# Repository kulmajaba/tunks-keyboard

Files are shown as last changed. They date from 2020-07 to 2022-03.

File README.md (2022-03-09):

# Tunks keyboards
> Formerly: The project that will someday be the ultimate command center upgrade

This repo contains the Tunks series keyboard schematics, born as an experiment to make a macro keyboard for editing, gaming and testing mechanical switches.

## Roadmap

Companion app: a combination of hardware and software allowing the user to control programs like Discord and OBS as well as receive visual feedback in the form of "tally lights".
Keyboard shortcuts are fragile and unpredictable, and software like AutoHotKey is considered cheating software by a lot of anti-cheat utilities, regardless of what you do with it.

**Resources**

- Discord: mute and deaf states, and setting the states instead of toggling: https://discordapp.com/developers/docs/game-sdk/discord-voice
- OBS: See which outputs are in use in the current scene (we're interested in camera, display capture and microphone), switch between scenes: https://obsproject.com/docs/
- QMK with SysEx Midi messages: https://beta.docs.qmk.fm/developing-qmk/qmk-internals-in-progress/internals_midi_device
- Keyboard PCB guide: https://wiki.ai03.com/books/pcb-design

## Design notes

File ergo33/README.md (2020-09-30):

# Ergo33

A left-hand keypad with a rotary encoder for gaming, video editing, macros etc.
* 33 keys plus rotary encoder with press switch
* Kailh hot-swap sockets
* Ergonomic layout (straight columns, staggered rows)
* LED underglow and the option to add an ergo33-led-board (or any other similar external PCB) for state indicators etc.

## Notes

* The WS2812B LEDs can be configured in three different ways and you may need to change hardware or firmware config:
  * Both underglow and external board in use: Bridge the solder jumper JP1 pads 1 and 2
  * Underglow in use, no external board: reduce the number of LEDs in firmware config
  * External board in use, no underglow: Bridge the solder jumper JP1 pads 2 and 3, reduce the number of LEDs in firmware config
* Spark suppression cap C19 may be omitted or resized, may affect bootloader activation time
* The highest component on the underside of the PCB is the USB-C connector at 3,15mm
* The rotary encoder position is sized for a 30mm knob

## BOM

| Component | Value | Quantity | Example | Notes |
| --- | ----- | --- | --- | ----- |
| ATmega32U4-AU TQFP-44 |  | 1 |  |  |
| Capacitor 0805 | 16pF | 2 |  | Crystal caps, size according to the crystal used |
| Capacitor 0805 | 510pF | 1 |  | Spark suppression capacitor C19 |
| Capacitor 0805 | 0.1uF | 19 |  |  |
| Capacitor 0805 | 1uF | 1 |  |  |
| Capacitor 0805 | 10uF | 2 |  |  |
| Crystal 3.2x2.5mm | 16MHz | 1 | DSX321G |  |
| Diode SOD-123 |  | 34 | 1N4148 |  |
| Fuse 1206 | 500mA | 1 | Littelfuse 1206L050/15 |  |
| Kailh Hot-swap Socket |  | 33 |  |  |
| LED WS2812B |  | 14 |  |  |
| Pin header 2.54mmx3 |  | 1 |  |  |
| Resistor 0805 | 22Ω | 2 |  |  |
| Resistor 0805 | 5.1kΩ | 2 |  |  |
| Resistor 0805 | 10kΩ | 2 |  |  |
| Rotary encoder EC11 |  | 1 |  |  |
| Switch 4x4mm SMD |  | 1 |  |  |
| USB-C 16 pin |  | 1 | HRO-TYPE-C-31-M-12 |  |
| USBLC6-2SC6 SOT-23-6 |  | 1 |  |  |
| M2 Mounting hardware |  | 12 |  |  |
| 30mm Encoder knob |  | 1 |  |  |

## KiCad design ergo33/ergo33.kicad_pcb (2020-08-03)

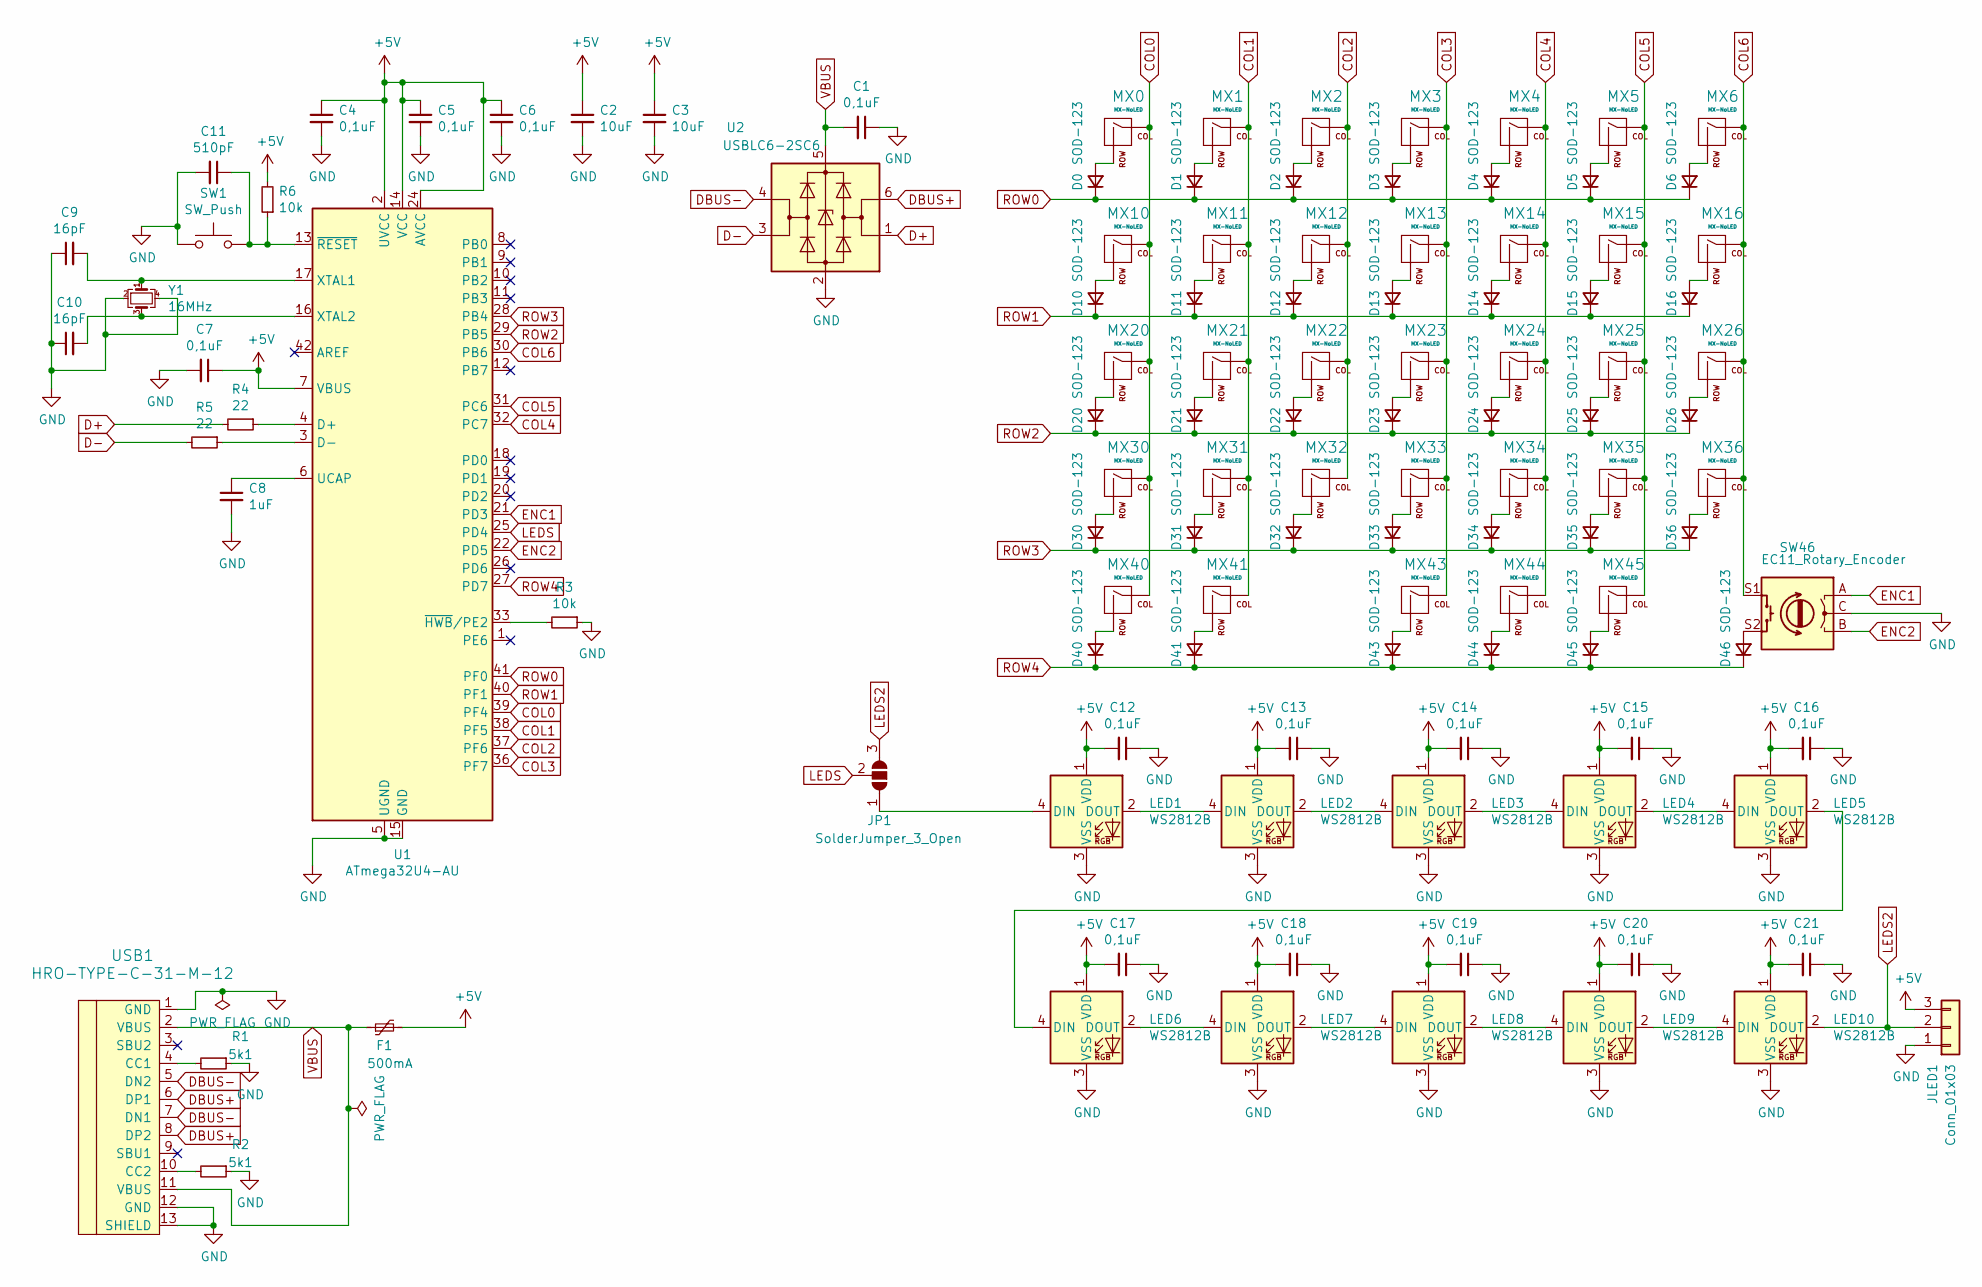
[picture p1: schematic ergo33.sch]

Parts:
C1, C4, C5, C6, C7, C12, C13, C14, C15, C16, C17, C18, C19, C20, C21: 0,1uF; C_0805_2012Metric_Pad1.15x1.40mm_HandSolder
C2, C3: 10uF; C_0805_2012Metric_Pad1.15x1.40mm_HandSolder
C8: 1uF; C_0805_2012Metric_Pad1.15x1.40mm_HandSolder
C9, C10: 16pF; C_0805_2012Metric_Pad1.15x1.40mm_HandSolder
C11: 510pF; C_0805_2012Metric_Pad1.15x1.40mm_HandSolder
D0, D1, D2, D3, D4, D5, D6, D10, D11, D12, D13, D14, D15, D16, D20, D21, D22, D23, D24, D25, D26, D30, D31, D32, D33, D34, D35, D36, D40, D41, D43, D44, D45, D46: SOD-123; D_SOD-123
F1: 500mA; Fuse_1206_3216Metric_Pad1.42x1.75mm_HandSolder
JLED1: Conn_01x03; PinHeader_1x03_P2.54mm_Vertical
JP1: SolderJumper_3_Open; SolderJumper-3_P1.3mm_Open_Pad1.0x1.5mm_NumberLabels
LED1, LED2, LED3, LED4, LED5, LED6, LED7, LED8, LED9, LED10: WS2812B; LED_WS2812B_PLCC4_5.0x5.0mm_P3.2mm
MX0, MX1, MX2, MX3, MX4, MX5, MX6, MX10, MX11, MX12, MX13, MX14, MX15, MX16, MX20, MX21, MX22, MX23, MX24, MX25, MX26, MX30, MX31, MX32, MX33, MX34, MX35, MX36, MX40, MX41, MX43, MX44, MX45: MX-NoLED; MXOnly-1U-Hotswap
R1, R2: 5k1; R_0805_2012Metric_Pad1.15x1.40mm_HandSolder
R3, R6: 10k; R_0805_2012Metric_Pad1.15x1.40mm_HandSolder
R4, R5: 22; R_0805_2012Metric_Pad1.15x1.40mm_HandSolder
SW1: SW_Push; SKQG-1155865
SW46: EC11_Rotary_Encoder; RotaryEncoder_Alps_EC11E-Switch_Vertical_H20mm
U1: ATmega32U4-AU; TQFP-44_10x10mm_P0.8mm
U2: USBLC6-2SC6; SOT-23-6_Handsoldering
USB1: HRO-TYPE-C-31-M-12; HRO-TYPE-C-31-M-12-HandSoldering
Y1: 16MHz; Crystal_SMD_3225-4Pin_3.2x2.5mm_HandSoldering

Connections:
+5V: C2.1, C3.1, C4.1, C5.1, C6.1, C7.1, C12.2, C13.2, C14.2, C15.2, C16.2, C17.2, C18.2, C19.2, C20.2, C21.2, F1.2, JLED1.3, LED1.1 (VDD), LED2.1 (VDD), LED3.1 (VDD), LED4.1 (VDD), LED5.1 (VDD), LED6.1 (VDD), LED7.1 (VDD), LED8.1 (VDD), LED9.1 (VDD), LED10.1 (VDD), R6.2, U1.2 (UVCC), U1.7 (VBUS), U1.14 (VCC), U1.24 (AVCC), U1.34 (VCC), U1.44 (AVCC)
COL0: MX0.1 (COL), MX10.1 (COL), MX20.1 (COL), MX30.1 (COL), MX40.1 (COL), U1.39 (PF4)
COL1: MX1.1 (COL), MX11.1 (COL), MX21.1 (COL), MX31.1 (COL), MX41.1 (COL), U1.38 (PF5)
COL2: MX2.1 (COL), MX12.1 (COL), MX22.1 (COL), MX32.1 (COL), U1.37 (PF6)
COL3: MX3.1 (COL), MX13.1 (COL), MX23.1 (COL), MX33.1 (COL), MX43.1 (COL), U1.36 (PF7)
COL4: MX4.1 (COL), MX14.1 (COL), MX24.1 (COL), MX34.1 (COL), MX44.1 (COL), U1.32 (PC7)
COL5: MX5.1 (COL), MX15.1 (COL), MX25.1 (COL), MX35.1 (COL), MX45.1 (COL), U1.31 (PC6)
COL6: MX6.1 (COL), MX16.1 (COL), MX26.1 (COL), MX36.1 (COL), SW46.S1, U1.30 (PB6)
D+: R4.2, U2.1 (I/O1)
D-: R5.2, U2.3 (I/O2)
DBUS+: U2.6 (I/O1), USB1.6 (DP1), USB1.8 (DP2)
DBUS-: U2.4 (I/O2), USB1.5 (DN2), USB1.7 (DN1)
ENC1: SW46.A, U1.21 (PD3)
ENC2: SW46.B, U1.22 (PD5)
GND: C1.1, C2.2, C3.2, C4.2, C5.2, C6.2, C7.2, C8.2, C9.1, C10.1, C11.2, C12.1, C13.1, C14.1, C15.1, C16.1, C17.1, C18.1, C19.1, C20.1, C21.1, JLED1.1, LED1.3 (VSS), LED2.3 (VSS), LED3.3 (VSS), LED4.3 (VSS), LED5.3 (VSS), LED6.3 (VSS), LED7.3 (VSS), LED8.3 (VSS), LED9.3 (VSS), LED10.3 (VSS), R1.1, R2.1, R3.1, SW1.1, SW46.C, U1.5 (UGND), U1.15 (GND), U1.23 (GND), U1.35 (GND), U1.43 (GND), U2.2 (GND), USB1.1 (GND), USB1.12 (GND), USB1.13 (SHIELD), Y1.2, Y1.4
LEDS: JP1.2 (C), U1.25 (PD4)
LEDS2: JLED1.2, JP1.3 (B), LED10.2 (DOUT)
unnamed: C8.1, U1.6 (UCAP)
unnamed: C9.2, U1.17 (XTAL1), Y1.1
unnamed: C10.2, U1.16 (XTAL2), Y1.3
unnamed: C11.1, R6.1, SW1.2, U1.13 (~RESET)
unnamed: D0.2 (A), MX0.2 (ROW)
unnamed: D1.2 (A), MX1.2 (ROW)
unnamed: D2.2 (A), MX2.2 (ROW)
unnamed: D3.2 (A), MX3.2 (ROW)
unnamed: D4.2 (A), MX4.2 (ROW)
unnamed: D5.2 (A), MX5.2 (ROW)
unnamed: D6.2 (A), MX6.2 (ROW)
unnamed: D10.2 (A), MX10.2 (ROW)
unnamed: D11.2 (A), MX11.2 (ROW)
unnamed: D12.2 (A), MX12.2 (ROW)
unnamed: D13.2 (A), MX13.2 (ROW)
unnamed: D14.2 (A), MX14.2 (ROW)
unnamed: D15.2 (A), MX15.2 (ROW)
unnamed: D16.2 (A), MX16.2 (ROW)
unnamed: D20.2 (A), MX20.2 (ROW)
unnamed: D21.2 (A), MX21.2 (ROW)
unnamed: D22.2 (A), MX22.2 (ROW)
unnamed: D23.2 (A), MX23.2 (ROW)
unnamed: D24.2 (A), MX24.2 (ROW)
unnamed: D25.2 (A), MX25.2 (ROW)
unnamed: D26.2 (A), MX26.2 (ROW)
unnamed: D30.2 (A), MX30.2 (ROW)
unnamed: D31.2 (A), MX31.2 (ROW)
unnamed: D32.2 (A), MX32.2 (ROW)
unnamed: D33.2 (A), MX33.2 (ROW)
unnamed: D34.2 (A), MX34.2 (ROW)
unnamed: D35.2 (A), MX35.2 (ROW)
unnamed: D36.2 (A), MX36.2 (ROW)
unnamed: D40.2 (A), MX40.2 (ROW)
unnamed: D41.2 (A), MX41.2 (ROW)
unnamed: D43.2 (A), MX43.2 (ROW)
unnamed: D44.2 (A), MX44.2 (ROW)
unnamed: D45.2 (A), MX45.2 (ROW)
unnamed: D46.2 (A), SW46.S2
unnamed: JP1.1 (A), LED1.4 (DIN)
unnamed: LED1.2 (DOUT), LED2.4 (DIN)
unnamed: LED2.2 (DOUT), LED3.4 (DIN)
unnamed: LED3.2 (DOUT), LED4.4 (DIN)
unnamed: LED4.2 (DOUT), LED5.4 (DIN)
unnamed: LED5.2 (DOUT), LED6.4 (DIN)
unnamed: LED6.2 (DOUT), LED7.4 (DIN)
unnamed: LED7.2 (DOUT), LED8.4 (DIN)
unnamed: LED8.2 (DOUT), LED9.4 (DIN)
unnamed: LED9.2 (DOUT), LED10.4 (DIN)
unnamed: R1.2, USB1.4 (CC1)
unnamed: R2.2, USB1.10 (CC2)
unnamed: R3.2, U1.33 (~HWB~/PE2)
unnamed: R4.1, U1.4 (D+)
unnamed: R5.1, U1.3 (D-)
ROW0: D0.1 (K), D1.1 (K), D2.1 (K), D3.1 (K), D4.1 (K), D5.1 (K), D6.1 (K), U1.41 (PF0)
ROW1: D10.1 (K), D11.1 (K), D12.1 (K), D13.1 (K), D14.1 (K), D15.1 (K), D16.1 (K), U1.40 (PF1)
ROW2: D20.1 (K), D21.1 (K), D22.1 (K), D23.1 (K), D24.1 (K), D25.1 (K), D26.1 (K), U1.29 (PB5)
ROW3: D30.1 (K), D31.1 (K), D32.1 (K), D33.1 (K), D34.1 (K), D35.1 (K), D36.1 (K), U1.28 (PB4)
ROW4: D40.1 (K), D41.1 (K), D43.1 (K), D44.1 (K), D45.1 (K), D46.1 (K), U1.27 (PD7)
VBUS: C1.2, F1.1, U2.5 (VBUS), USB1.2 (VBUS), USB1.11 (VBUS)

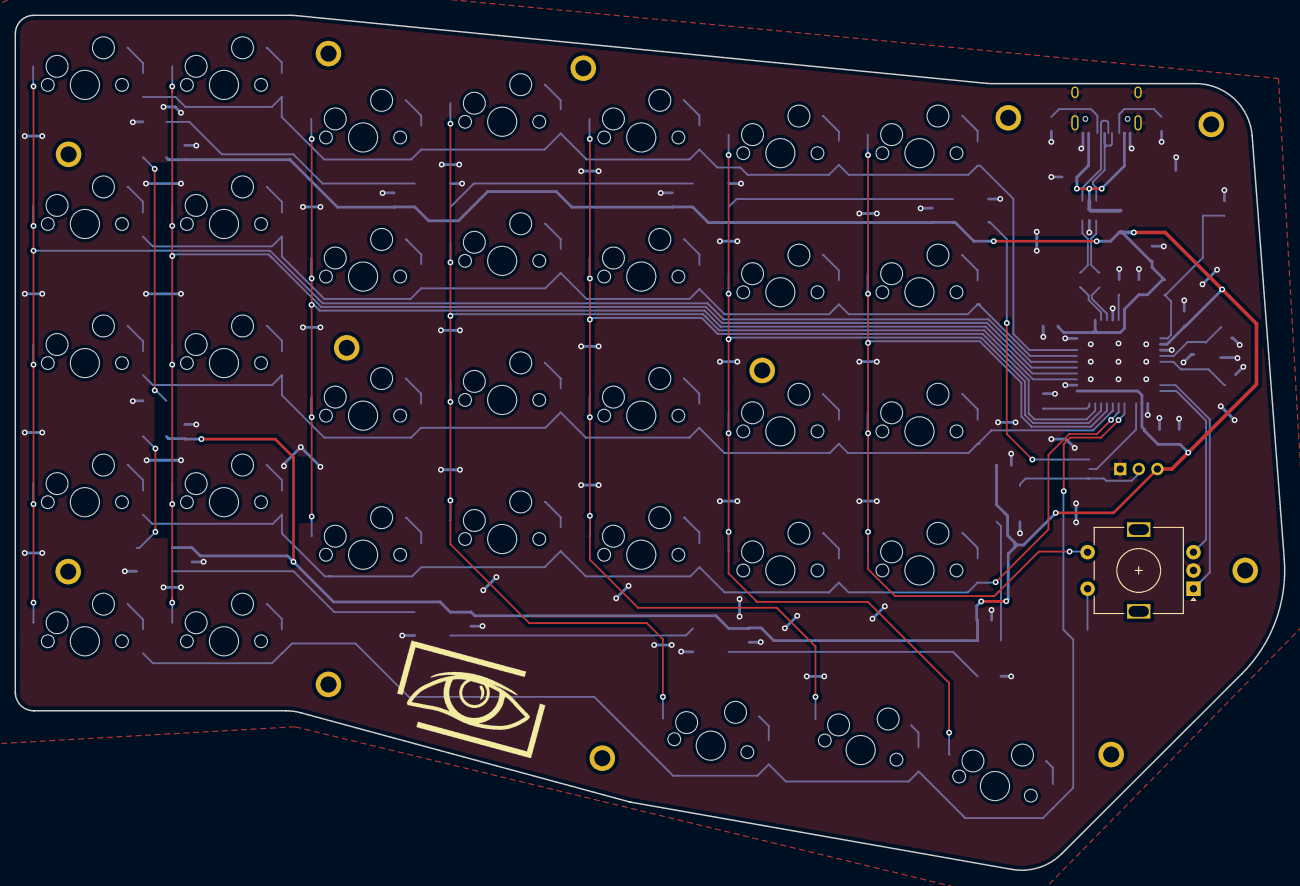
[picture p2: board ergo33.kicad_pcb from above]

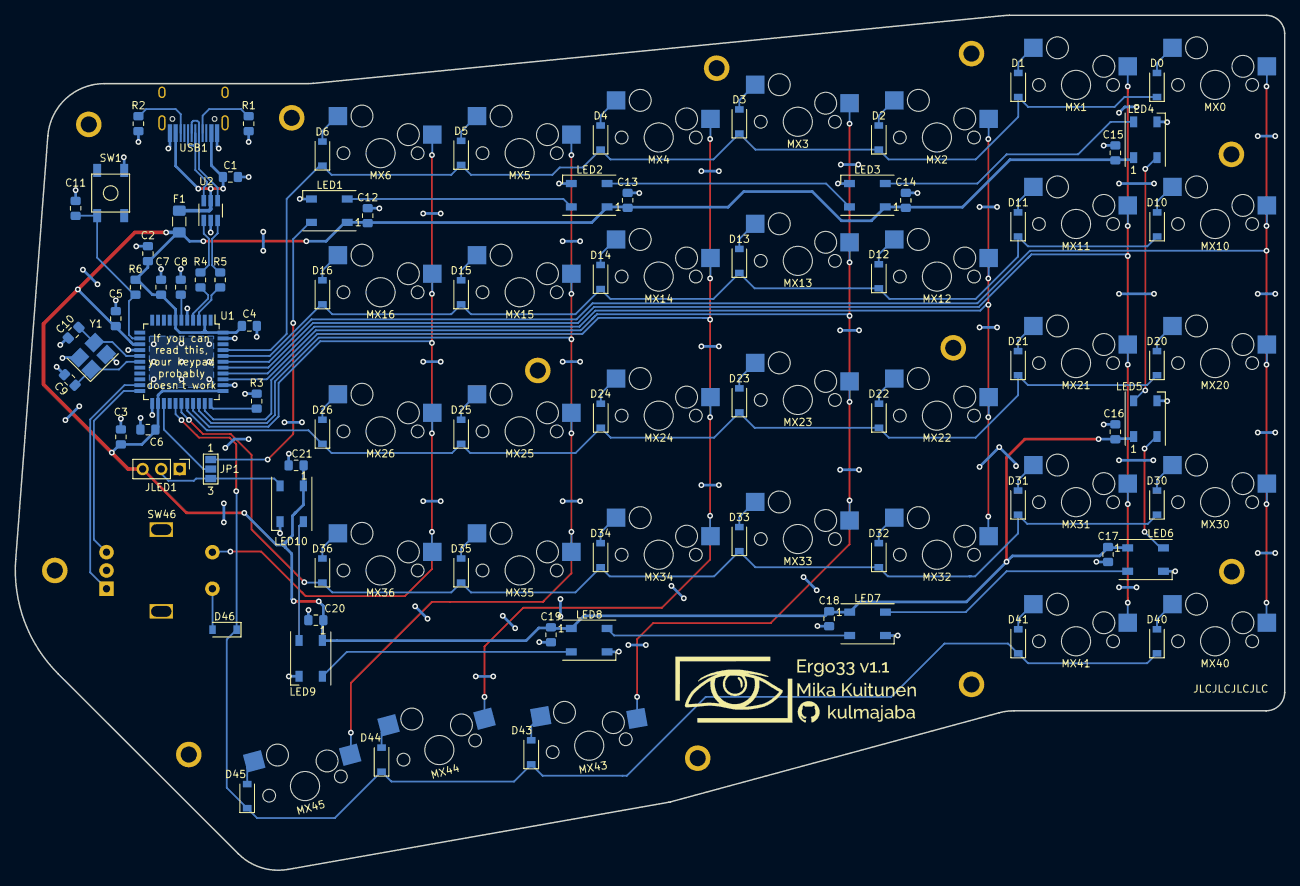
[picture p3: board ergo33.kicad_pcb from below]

Board: 2 copper layers, 173.8 x 117.1 mm, 113 parts (79 on the bottom side), 76 nets.

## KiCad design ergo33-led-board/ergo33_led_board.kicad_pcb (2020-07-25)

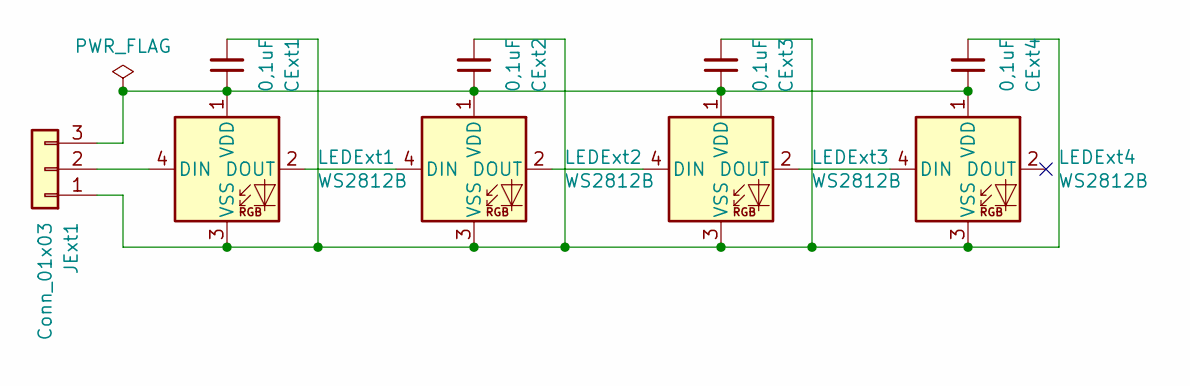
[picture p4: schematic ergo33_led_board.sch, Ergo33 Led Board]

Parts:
CExt1, CExt2, CExt3, CExt4: 0,1uF; C_0805_2012Metric_Pad1.15x1.40mm_HandSolder
JExt1: Conn_01x03; PinHeader_1x03_P2.54mm_Vertical
LEDExt1, LEDExt2, LEDExt3, LEDExt4: WS2812B; LED_WS2812B_PLCC4_5.0x5.0mm_P3.2mm

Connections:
unnamed: CExt1.1, CExt2.1, CExt3.1, CExt4.1, JExt1.3, LEDExt1.1 (VDD), LEDExt2.1 (VDD), LEDExt3.1 (VDD), LEDExt4.1 (VDD)
unnamed: CExt1.2, CExt2.2, CExt3.2, CExt4.2, JExt1.1, LEDExt1.3 (VSS), LEDExt2.3 (VSS), LEDExt3.3 (VSS), LEDExt4.3 (VSS)
unnamed: JExt1.2, LEDExt1.4 (DIN)
unnamed: LEDExt1.2 (DOUT), LEDExt2.4 (DIN)
unnamed: LEDExt2.2 (DOUT), LEDExt3.4 (DIN)
unnamed: LEDExt3.2 (DOUT), LEDExt4.4 (DIN)

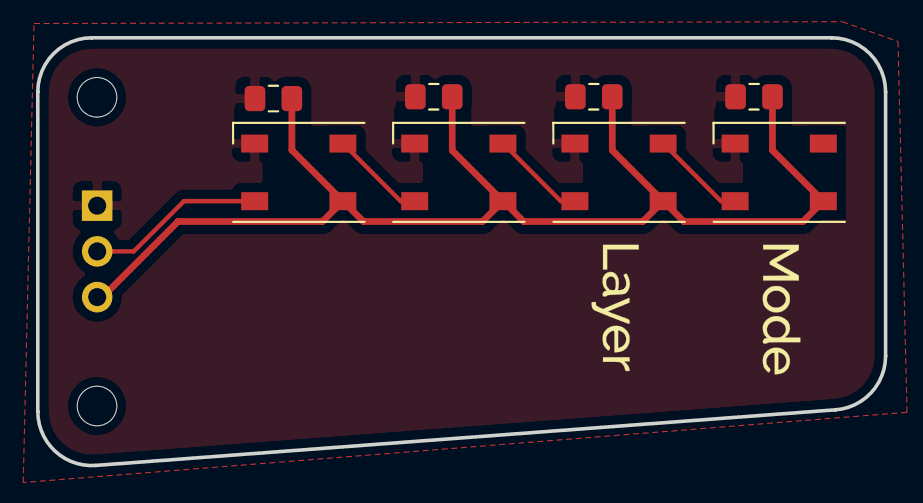
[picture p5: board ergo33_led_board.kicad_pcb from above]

Board: 2 copper layers, 47.1 x 23.8 mm, 11 parts (1 on the bottom side), 6 nets.

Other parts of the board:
M1, M2: MountingHole_2.2mm_M2_ISO7380

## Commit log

2020-07-19 Add ergo33 base
    [ergo33.kicad_pcb, ergo33.sch]
2020-07-23 Start trace layout
    [ergo33.kicad_pcb, ergo33.sch]
2020-07-23 Rerouting ergo33
    [ergo33.kicad_pcb, ergo33.sch]
2020-07-23 Finish ergo33 routing v1
    [ergo33.kicad_pcb, ergo33.sch]
2020-07-23 Fix ergo33 routing
    [ergo33.kicad_pcb, ergo33.sch]
2020-07-24 Add arc suppression cap to ergo33
    [ergo33.kicad_pcb, ergo33.sch]
2020-07-24 Reroute ergo33 MCU area
    [ergo33.kicad_pcb, ergo33.sch]
2020-07-24 Minor routing fix to ergo33
    [ergo33.kicad_pcb]
2020-07-24 ergo33 minor fixes
    [ergo33.kicad_pcb]
2020-07-24 Fix DRC errors
    [ergo33.kicad_pcb]
2020-07-24 ergo33: Change USB connectors and add ESD protection
    [ergo33.kicad_pcb, ergo33.sch]
2020-07-24 Add mounting holes and tweak silkscreen
    [ergo33.kicad_pcb, ergo33.sch]
2020-07-24 ergo33: footprint changes
    [ergo33.kicad_pcb]
2020-07-24 ergo33: fix a derp
    [ergo33.kicad_pcb]
2020-07-24 Add external light PCB
    [ergo33.kicad_pcb, ergo33.sch]
2020-07-24 ergo33: minor cleanup
    [ergo33.kicad_pcb]
2020-07-24 ergo33: minor tweaking
    [ergo33.kicad_pcb]
2020-07-24 ergo33: Panelize maybe?
    [ergo33-B_Cu.gbl, ergo33-B_Mask.gbs, ergo33-B_SilkS.gbo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]
2020-07-25 Ergo33: add graphics
    [ergo33.kicad_pcb]
2020-07-25 Ergo33: archive footprints
2020-07-25 Ergo33: refill ground
2020-07-25 Ergo33: depanelize :(
    [ergo33-B_Cu.gbl, ergo33-B_Mask.gbs, ergo33-B_SilkS.gbo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]
2020-07-25 Ergo33: generate gerbers
    [ergo33-B_Cu.gbl, ergo33-B_Mask.gbs, ergo33-B_SilkS.gbo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]
2020-07-25 Ergo33: update LED PCB gerbers
    [ergo33_led_board-B_Cu.gbl, ergo33_led_board-B_Mask.gbs, ergo33_led_board-B_SilkS.gbo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]
2020-07-27 Change a few cap values
    [ergo33.kicad_pcb, ergo33.sch]
2020-08-03 Ergo33: rev2
    [ergo33-B_Cu.gbl, ergo33-B_Mask.gbs, ergo33-B_SilkS.gbo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]
2020-08-03 Ergo33: Change logo to v1.1
    [ergo33-B_Cu.gbl, ergo33-B_Mask.gbs, ergo33-B_SilkS.gbo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]
2020-09-30 Add Readme and BOM for Ergo33
